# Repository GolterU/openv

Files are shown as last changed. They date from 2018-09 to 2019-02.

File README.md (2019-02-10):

### Heizungssteuerung und -überwachung per Optolink-Schnittstelle
Für die Windows-Software ["Viess-ion"](https://github.com/openv/openv/wiki/Vies-sion) werden hier die passenden Parameter-Dateien bearbeitet, damit sie zur Heizungsanlage passen. Die Kommunikation zwischen Steuer-PC und der Heizung erfolgt mithilfe des Adapters ["Optolink-Duo/Sniffer"](https://github.com/openv/openv/wiki/Bauanleitung-USB_Duo-Sniffer).<p>
Die Heizungsanlage besteht aus dem Gaswandgerät "Vitodens 300-W" WB3C, Code: CB und zwei Heizkreisen. <br>
Kreis A1 für die Heizkörper hängt über die interne Heizungspumpe direkt am Kessel. Kreis M2 für die Räume mit Fußbodenheizung über einen Drei-Wege-Mischer, der am KM-Bus angeschlossen ist. Es wird zusätzlich ein 300-Liter-Boiler zur Warmwasserbereitung betrieben. Die Warmwasserverteilung im Haus erfolgt mit Hilfe einer zeitgesteuerten Zirkulationspumpe, die ihrerseits an der externen Erweiterung H1 hängt.<br>
Die Heizungssteuerung erfolgt intern mit der herstellereigenen Vitotronic. Die Heizkreise des Hauses jedoch über eine selbstentwickelte Steuerung ["HSC"](https://godemann.de/Controller/Hauscomputer/hauscomputer.html), die ohne Eingriff in die Heizungssteuerung auskommt.

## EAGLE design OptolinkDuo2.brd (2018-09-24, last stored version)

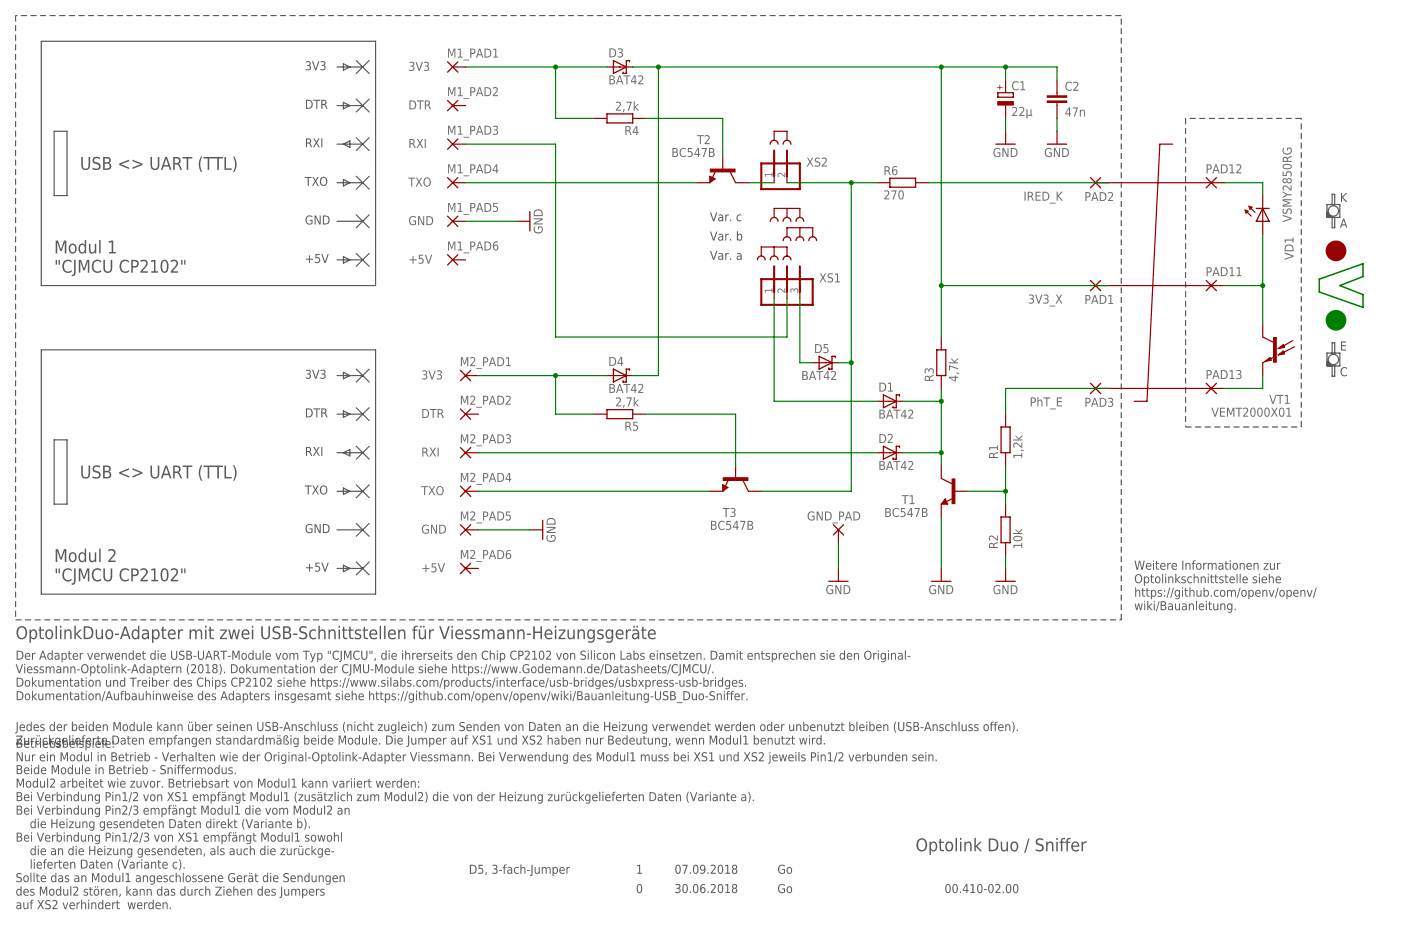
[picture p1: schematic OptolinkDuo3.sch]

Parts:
3V3_XE: V; V-PAC
C1: 22µ; E2,5-5
C2: 47n; C050-024X044
D1, D2, D3, D4, D5: BAT42; DO35-10
GND_PAD: GND; 2,15/1,0
J1, J2: JUMPER; JUMP
M1_PAD1, M2_PAD1: 3V3; 2,15/1,0
M1_PAD2, M2_PAD2: DTR; 2,15/1,0
M1_PAD3, M2_PAD3: RXI; 2,15/1,0
M1_PAD4, M2_PAD4: TXO; 2,15/1,0
M1_PAD5, M2_PAD5: GND; 2,15/1,0
M1_PAD6, M2_PAD6: +5V; 2,15/1,0
PAD1: 3V3_X; 1,6/0,8
PAD2: IRED_K; 1,6/0,8
PAD3: PhT_E; 1,6/0,8
PAD11: 3V3_x; SMD1,27-2,54
PAD12: IRED_K; SMD1,27-2,54
PAD13: PhT_E; SMD1,27-2,54
R1: 1,2k; 0207/10
R2: 10k; 0207/10
R3: 4,7k; 0207/10
R4, R5: 2,7k; 0207/10
R6: 270; 0207/10
T1, T2, T3: BC547B; TO92-CBE
VD1: VSMY2850RG; VISHAY_GULLWING(R)
VT1: VEMT2000X01; VISHAY_GULLWING(R)
XS1: PINHD-1X3; 1X03
XS2: PINHD-1X2; 1X02

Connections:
3V3_1: D3.A, M1_PAD1.1, R4.2
3V3_2: D4.A, M2_PAD1.1, R5.2
3V3_X: C1.+, C2.1, D3.C, D4.C, PAD1.1, R3.2
3V3_XE: PAD11.1, VD1.COLLECTOR (A), VT1.COLLECTOR (C)
GND: C1.-, C2.2, GND_PAD.1, M1_PAD5.1, M2_PAD5.1, R2.1, T1.E
unnamed: T2.C, XS2.1
unnamed: D2.A, M2_PAD3.1
unnamed: D1.A, XS1.1
unnamed: D5.C, R6.1, T3.C, XS2.2
unnamed: PAD12.1, VD1.EMITTER (C)
unnamed: PAD13.1, VT1.EMITTER (E)
unnamed: D5.A, XS1.3
unnamed: PAD3.1, R1.2
unnamed: R1.1, R2.2, T1.B
unnamed: D1.C, D2.C, R3.1, T1.C
unnamed: M1_PAD3.1, XS1.2
unnamed: R5.1, T3.B
unnamed: R4.1, T2.B
unnamed: PAD2.1, R6.2
TXO_1: M1_PAD4.1, T2.E
TXO_2: M2_PAD4.1, T3.E

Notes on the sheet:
Optolink Duo / Sniffer
00.410-02.00
Modul 1 "CJMCU CP2102"
3V3
DTR
RXI
TXO
GND
+5V
USB <> UART (TTL)
Modul 2 "CJMCU CP2102"
30.06.2018
OptolinkDuo-Adapter mit zwei USB-Schnittstellen für Viessmann-Heizungsgeräte
Der Adapter verwendet die USB-UART-Module vom Typ "CJMCU", die ihrerseits den Chip CP2102 von Silicon Labs einsetzen. Damit entsprechen sie den Original- Viessmann-Optolink-Adaptern (2018). Dokumentation der CJMU-Module siehe https://www.Godemann.de/Datasheets/CJMCU/. Dokumentation und Treiber des 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
Beide Module in Betrieb - Sniffermodus. Modul2 arbeitet wie zuvor. Betriebsart von Modul1 kann variiert werden: Bei Verbindung Pin1/2 von XS1 empfängt Modul1 (zusätzlich zum Modul2) die von der Heizung zurückgelieferten Daten (Variante a). Bei Verbindung Pin2/3 empfängt Modul1 die vom Modul2 an die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
Jedes der beiden Module kann über seinen USB-Anschluss (nicht zugleich) zum Senden von Daten an die Heizung verwendet werden oder unbenutzt bleiben (USB-Anschluss offen). Zurückgelieferte Daten empfangen standardmäßig beide Module. Die Jumper auf XS1 und XS2 haben nur Bedeutung, wenn Modul1 benutzt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
Weitere Informationen zur Optolinkschnittstelle siehe https://github.com/openv/openv/ wiki/Bauanleitung.
07.09.2018
D5, 3-fach-Jumper
Betriebsbeispiele: Nur ein Modul in Betrieb - Verhalten wie der Original-Optolink-Adapter Viessmann. Bei Verwendung des Modul1 muss bei XS1 und XS2 jeweils Pin1/2 verbunden sein.
Var. a
Var. b
Var. c

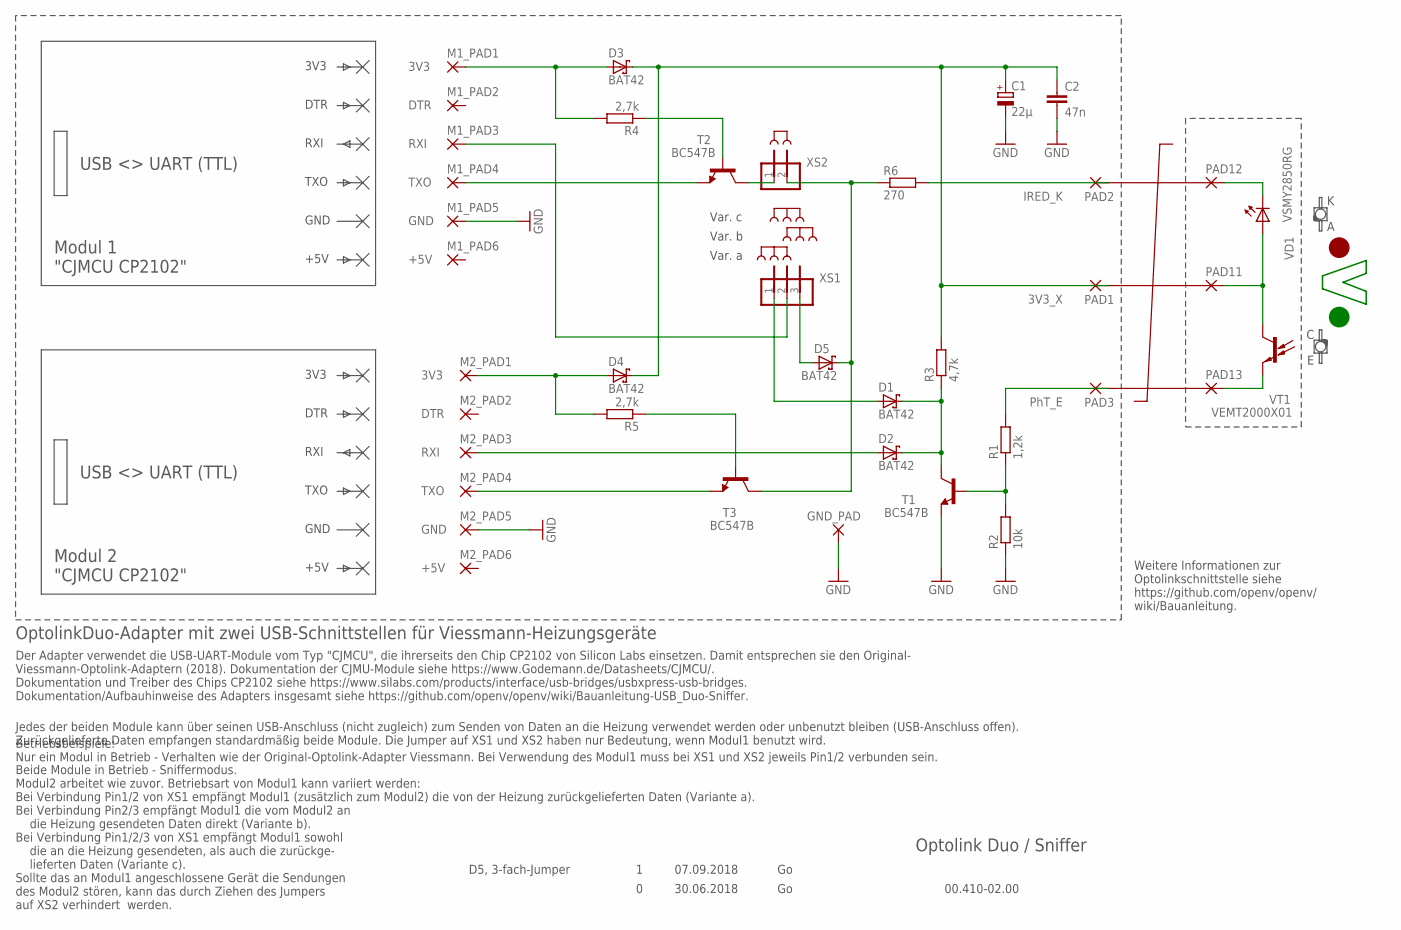
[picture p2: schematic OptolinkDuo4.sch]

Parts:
3V3_XE: V; V-PAC
C1: 22µ; E2,5-5
C2: 47n; C050-024X044
D1, D2, D3, D4, D5: BAT42; DO35-10
GND_PAD: GND; 2,15/1,0
J1, J2: JUMPER; JUMP
M1_PAD1, M2_PAD1: 3V3; 2,15/1,0
M1_PAD2, M2_PAD2: DTR; 2,15/1,0
M1_PAD3, M2_PAD3: RXI; 2,15/1,0
M1_PAD4, M2_PAD4: TXO; 2,15/1,0
M1_PAD5, M2_PAD5: GND; 2,15/1,0
M1_PAD6, M2_PAD6: +5V; 2,15/1,0
PAD1: 3V3_X; 1,6/0,8
PAD2: IRED_K; 1,6/0,8
PAD3: PhT_E; 1,6/0,8
PAD11: 3V3_x; SMD1,27-2,54
PAD12: IRED_K; SMD1,27-2,54
PAD13: PhT_E; SMD1,27-2,54
R1: 1,2k; 0207/10
R2: 10k; 0207/10
R3: 4,7k; 0207/10
R4, R5: 2,7k; 0207/10
R6: 270; 0207/10
T1, T2, T3: BC547B; TO92-CBE
VD1: VSMY2850RG; VISHAY_GULLWING(R)
VT1: VEMT2000X01; VISHAY_GULLWING(R)
XS1: PINHD-1X3; 1X03
XS2: PINHD-1X2; 1X02

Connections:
3V3_1: D3.A, M1_PAD1.1, R4.2
3V3_2: D4.A, M2_PAD1.1, R5.2
3V3_X: C1.+, C2.1, D3.C, D4.C, PAD1.1, R3.2
3V3_XE: PAD11.1, VD1.COLLECTOR (A), VT1.COLLECTOR (C)
GND: C1.-, C2.2, GND_PAD.1, M1_PAD5.1, M2_PAD5.1, R2.1, T1.E
unnamed: T2.C, XS2.1
unnamed: D2.A, M2_PAD3.1
unnamed: D1.A, XS1.1
unnamed: D5.C, R6.1, T3.C, XS2.2
unnamed: PAD12.1, VD1.EMITTER (C)
unnamed: PAD13.1, VT1.EMITTER (E)
unnamed: D5.A, XS1.3
unnamed: PAD3.1, R1.2
unnamed: R1.1, R2.2, T1.B
unnamed: D1.C, D2.C, R3.1, T1.C
unnamed: M1_PAD3.1, XS1.2
unnamed: R5.1, T3.B
unnamed: R4.1, T2.B
unnamed: PAD2.1, R6.2
TXO_1: M1_PAD4.1, T2.E
TXO_2: M2_PAD4.1, T3.E

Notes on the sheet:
Optolink Duo / Sniffer
00.410-02.00
Modul 1 "CJMCU CP2102"
3V3
DTR
RXI
TXO
GND
+5V
USB <> UART (TTL)
Modul 2 "CJMCU CP2102"
30.06.2018
OptolinkDuo-Adapter mit zwei USB-Schnittstellen für Viessmann-Heizungsgeräte
Der Adapter verwendet die USB-UART-Module vom Typ "CJMCU", die ihrerseits den Chip CP2102 von Silicon Labs einsetzen. Damit entsprechen sie den Original- Viessmann-Optolink-Adaptern (2018). Dokumentation der CJMU-Module siehe https://www.Godemann.de/Datasheets/CJMCU/. Dokumentation und Treiber des 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
Beide Module in Betrieb - Sniffermodus. Modul2 arbeitet wie zuvor. Betriebsart von Modul1 kann variiert werden: Bei Verbindung Pin1/2 von XS1 empfängt Modul1 (zusätzlich zum Modul2) die von der Heizung zurückgelieferten Daten (Variante a). Bei Verbindung Pin2/3 empfängt Modul1 die vom Modul2 an die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
Jedes der beiden Module kann über seinen USB-Anschluss (nicht zugleich) zum Senden von Daten an die Heizung verwendet werden oder unbenutzt bleiben (USB-Anschluss offen). Zurückgelieferte Daten empfangen standardmäßig beide Module. Die Jumper auf XS1 und XS2 haben nur Bedeutung, wenn Modul1 benutzt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
Weitere Informationen zur Optolinkschnittstelle siehe https://github.com/openv/openv/ wiki/Bauanleitung.
07.09.2018
D5, 3-fach-Jumper
Betriebsbeispiele: Nur ein Modul in Betrieb - Verhalten wie der Original-Optolink-Adapter Viessmann. Bei Verwendung des Modul1 muss bei XS1 und XS2 jeweils Pin1/2 verbunden sein.
Var. a
Var. b
Var. c

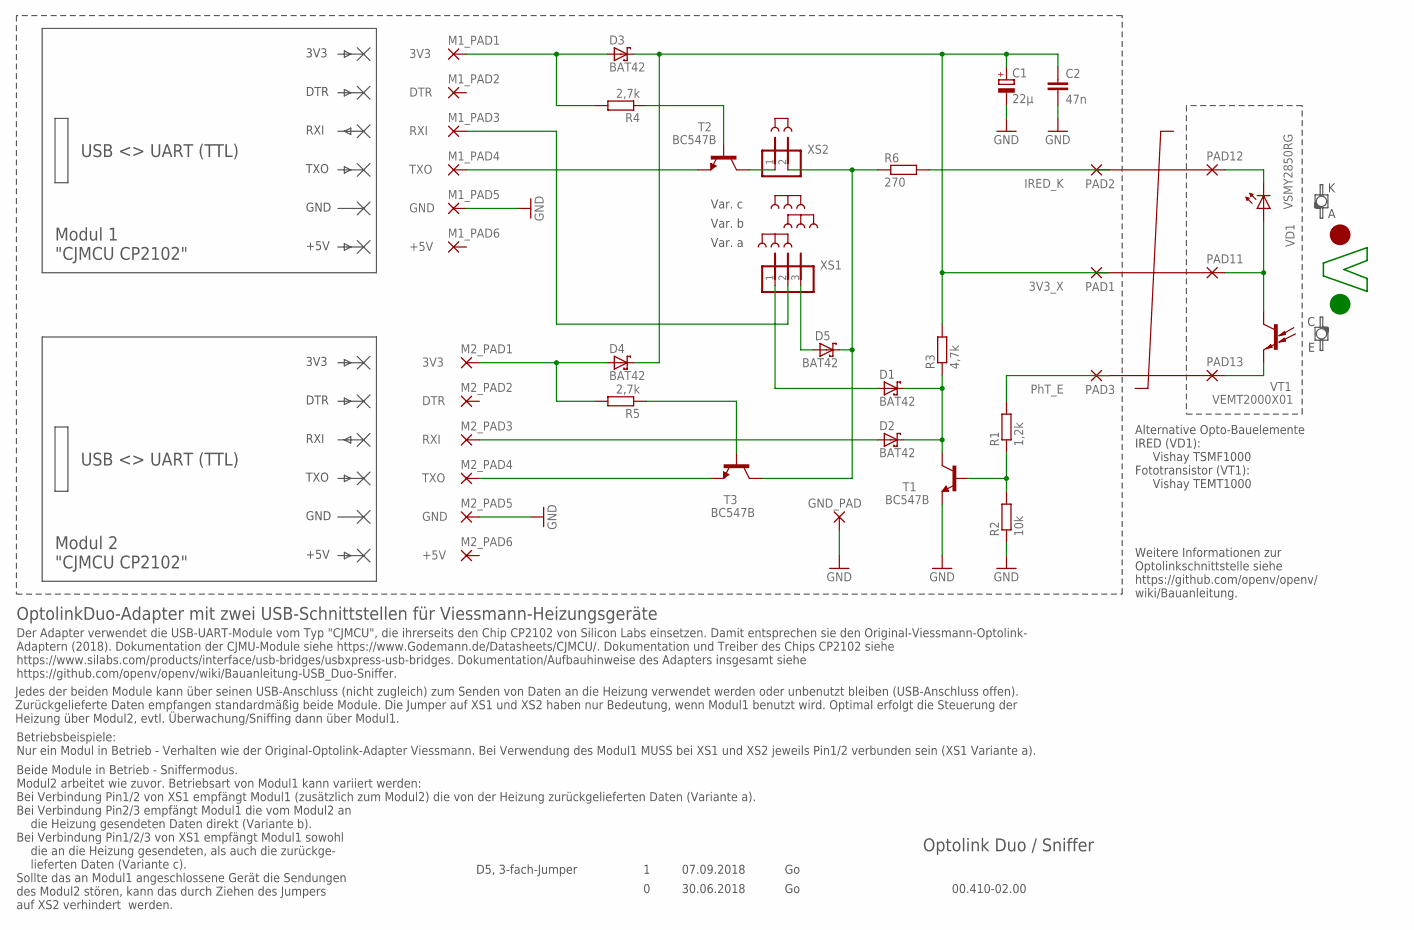
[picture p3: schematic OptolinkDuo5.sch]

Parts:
3V3_XE: V; V-PAC
C1: 22µ; E2,5-5
C2: 47n; C050-024X044
D1, D2, D3, D4, D5: BAT42; DO35-10
GND_PAD: GND; 2,15/1,0
J1, J2: JUMPER; JUMP
M1_PAD1, M2_PAD1: 3V3; 2,15/1,0
M1_PAD2, M2_PAD2: DTR; 2,15/1,0
M1_PAD3, M2_PAD3: RXI; 2,15/1,0
M1_PAD4, M2_PAD4: TXO; 2,15/1,0
M1_PAD5, M2_PAD5: GND; 2,15/1,0
M1_PAD6, M2_PAD6: +5V; 2,15/1,0
PAD1: 3V3_X; 1,6/0,8
PAD2: IRED_K; 1,6/0,8
PAD3: PhT_E; 1,6/0,8
PAD11: 3V3_x; SMD1,27-2,54
PAD12: IRED_K; SMD1,27-2,54
PAD13: PhT_E; SMD1,27-2,54
R1: 1,2k; 0207/10
R2: 10k; 0207/10
R3: 4,7k; 0207/10
R4, R5: 2,7k; 0207/10
R6: 270; 0207/10
T1, T2, T3: BC547B; TO92-CBE
VD1: VSMY2850RG; VISHAY_GULLWING(R)
VT1: VEMT2000X01; VISHAY_GULLWING(R)
XS1: PINHD-1X3; 1X03
XS2: PINHD-1X2; 1X02

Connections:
3V3_1: D3.A, M1_PAD1.1, R4.2
3V3_2: D4.A, M2_PAD1.1, R5.2
3V3_X: C1.+, C2.1, D3.C, D4.C, PAD1.1, R3.2
3V3_XE: PAD11.1, VD1.COLLECTOR (A), VT1.COLLECTOR (C)
GND: C1.-, C2.2, GND_PAD.1, M1_PAD5.1, M2_PAD5.1, R2.1, T1.E
unnamed: T2.C, XS2.1
unnamed: D2.A, M2_PAD3.1
unnamed: D1.A, XS1.1
unnamed: D5.C, R6.1, T3.C, XS2.2
unnamed: PAD12.1, VD1.EMITTER (C)
unnamed: PAD13.1, VT1.EMITTER (E)
unnamed: D5.A, XS1.3
unnamed: PAD3.1, R1.2
unnamed: R1.1, R2.2, T1.B
unnamed: D1.C, D2.C, R3.1, T1.C
unnamed: M1_PAD3.1, XS1.2
unnamed: R5.1, T3.B
unnamed: R4.1, T2.B
unnamed: PAD2.1, R6.2
TXO_1: M1_PAD4.1, T2.E
TXO_2: M2_PAD4.1, T3.E

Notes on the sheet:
Optolink Duo / Sniffer
00.410-02.00
Modul 1 "CJMCU CP2102"
3V3
DTR
RXI
TXO
GND
+5V
USB <> UART (TTL)
Modul 2 "CJMCU CP2102"
30.06.2018
OptolinkDuo-Adapter mit zwei USB-Schnittstellen für Viessmann-Heizungsgeräte
Der Adapter verwendet die USB-UART-Module vom Typ "CJMCU", die ihrerseits den Chip CP2102 von Silicon Labs einsetzen. Damit entsprechen sie den Original-Viessmann-Optolink- Adaptern (2018). Dokumentation der CJMU-Module siehe https://www.Godemann.de/Datasheets/CJMCU/. Dokumentation und Treiber des 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
Beide Module in Betrieb - Sniffermodus. Modul2 arbeitet wie zuvor. Betriebsart von Modul1 kann variiert werden: Bei Verbindung Pin1/2 von XS1 empfängt Modul1 (zusätzlich zum Modul2) die von der Heizung zurückgelieferten Daten (Variante a). Bei Verbindung Pin2/3 empfängt Modul1 die vom Modul2 an die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
Jedes der beiden Module kann über seinen USB-Anschluss (nicht zugleich) zum Senden von Daten an die Heizung verwendet werden oder unbenutzt bleiben (USB-Anschluss offen). Zurückgelieferte Daten empfangen standardmäßig beide Module. Die Jumper auf XS1 und XS2 haben nur Bedeutung, wenn Modul1 benutzt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
Weitere Informationen zur Optolinkschnittstelle siehe https://github.com/openv/openv/ wiki/Bauanleitung.
07.09.2018
D5, 3-fach-Jumper
Betriebsbeispiele: Nur ein Modul in Betrieb - Verhalten wie der Original-Optolink-Adapter Viessmann. Bei Verwendung des Modul1 MUSS bei XS1 und XS2 jeweils Pin1/2 verbunden sein (XS1 Variante a).
Var. a
Var. b
Var. c
Alternative Opto-Bauelemente IRED (VD1): Vishay TSMF1000 Fototransistor (VT1): Vishay TEMT1000


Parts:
3V3_XE: V; V-PAC
C1: 22µ; E2,5-5
C2: 47n; C050-024X044
D1, D2, D3, D4, D5: BAT42; DO35-10
GND_PAD: GND; 2,15/1,0
J1, J2: JUMPER; JUMP
M1_PAD1, M2_PAD1: 3V3; 2,15/1,0
M1_PAD2, M2_PAD2: DTR; 2,15/1,0
M1_PAD3, M2_PAD3: RXI; 2,15/1,0
M1_PAD4, M2_PAD4: TXO; 2,15/1,0
M1_PAD5, M2_PAD5: GND; 2,15/1,0
M1_PAD6, M2_PAD6: +5V; 2,15/1,0
PAD1: 3V3_X; 1,6/0,8
PAD2: IRED_K; 1,6/0,8
PAD3: PhT_E; 1,6/0,8
PAD11: 3V3_x; SMD1,27-2,54
PAD12: IRED_K; SMD1,27-2,54
PAD13: PhT_E; SMD1,27-2,54
R1: 1,2k; 0207/10
R2: 10k; 0207/10
R3: 4,7k; 0207/10
R4, R5: 2,7k; 0207/10
R6: 270; 0207/10
T1, T2, T3: BC547B; TO92-CBE
VD1: VSMY2850RG; VISHAY_GULLWING(R)
VT1: VEMT2000X01; VISHAY_GULLWING(R)
XS1: PINHD-1X3; 1X03
XS2: PINHD-1X2; 1X02

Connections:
3V3_1: D3.A, M1_PAD1.1, R4.2
3V3_2: D4.A, M2_PAD1.1, R5.2
3V3_X: C1.+, C2.1, D3.C, D4.C, PAD1.1, R3.2
3V3_XE: PAD11.1, VD1.COLLECTOR (A), VT1.COLLECTOR (C)
GND: C1.-, C2.2, GND_PAD.1, M1_PAD5.1, M2_PAD5.1, R2.1, T1.E
unnamed: T2.C, XS2.1
unnamed: D2.A, M2_PAD3.1
unnamed: D1.A, XS1.1
unnamed: D5.C, R6.1, T3.C, XS2.2
unnamed: PAD12.1, VD1.EMITTER (C)
unnamed: PAD13.1, VT1.EMITTER (E)
unnamed: D5.A, XS1.3
unnamed: PAD3.1, R1.2
unnamed: R1.1, R2.2, T1.B
unnamed: D1.C, D2.C, R3.1, T1.C
unnamed: M1_PAD3.1, XS1.2
unnamed: R5.1, T3.B
unnamed: R4.1, T2.B
unnamed: PAD2.1, R6.2
TXO_1: M1_PAD4.1, T2.E
TXO_2: M2_PAD4.1, T3.E

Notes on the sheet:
Optolink Duo / Sniffer
00.410-02.00
Modul 1 "CJMCU CP2102"
3V3
DTR
RXI
TXO
GND
+5V
USB <> UART (TTL)
Modul 2 "CJMCU CP2102"
30.06.2018
OptolinkDuo-Adapter mit zwei USB-Schnittstellen für Viessmann-Heizungsgeräte
Der Adapter verwendet die USB-UART-Module vom Typ "CJMCU", die ihrerseits den Chip CP2102 von Silicon Labs einsetzen. Damit entsprechen sie den Original- Viessmann-Optolink-Adaptern (2018). Dokumentation der CJMU-Module siehe https://www.Godemann.de/Datasheets/CJMCU/. Dokumentation und Treiber des 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
Beide Module in Betrieb - Sniffermodus. Modul2 arbeitet wie zuvor. Betriebsart von Modul1 kann variiert werden: Bei Verbindung Pin1/2 von XS1 empfängt Modul1 (zusätzlich zum Modul2) die von der Heizung zurückgelieferten Daten (Variante a). Bei Verbindung Pin2/3 empfängt Modul1 die vom Modul2 an die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
Jedes der beiden Module kann über seinen USB-Anschluss (nicht zugleich) zum Senden von Daten an die Heizung verwendet werden oder unbenutzt bleiben (USB-Anschluss offen). Zurückgelieferte Daten empfangen standardmäßig beide Module. Die Jumper auf XS1 und XS2 haben nur Bedeutung, wenn Modul1 benutzt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
Weitere Informationen zur Optolinkschnittstelle siehe https://github.com/openv/openv/ wiki/Bauanleitung.
07.09.2018
D5, 3-fach-Jumper
Betriebsbeispiele: Nur ein Modul in Betrieb - Verhalten wie der Original-Optolink-Adapter Viessmann. Bei Verwendung des Modul1 muss bei XS1 und XS2 jeweils Pin1/2 verbunden sein.
Var. a
Var. b
Var. c

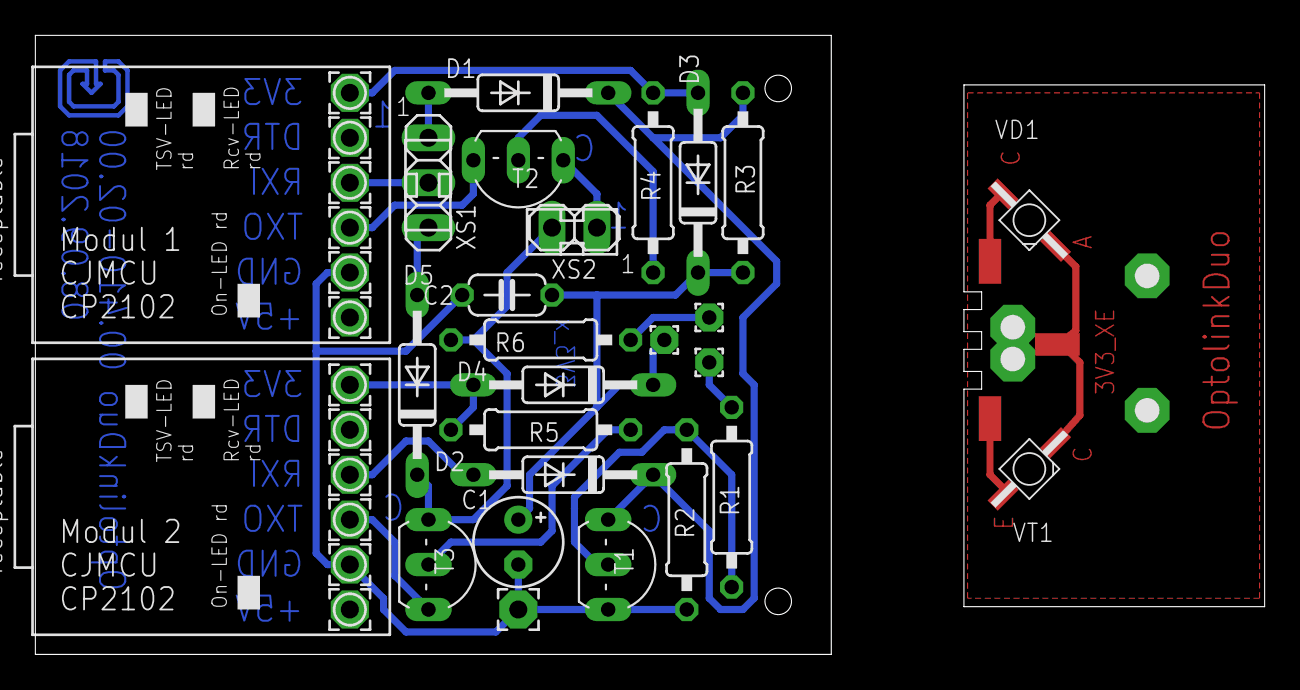
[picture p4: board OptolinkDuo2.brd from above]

Board: 2 copper layers, 45.0 x 35.0 mm, 43 parts (0 on the bottom side), 21 nets.

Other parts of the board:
U$4: !G-SIGN_B

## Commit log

2019-02-10 Unnötige Dateien gelöscht
    [OptolinkDuo2.brd, OptolinkDuo4.sch, OptolinkDuo5.sch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]
2019-02-11 "Raum Temperatur Ist-Wert" (0898) aus Kat. Sensor entfernt
